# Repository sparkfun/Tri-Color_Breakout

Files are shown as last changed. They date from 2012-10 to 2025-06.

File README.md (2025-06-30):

Tri-Color LED Breakout Kit
==========================

[Tri-Color LED Breakout Kit  
*Tri-Color LED Breakout Kit (KIT-10111)*](https://www.sparkfun.com/products/10111)

A simple breakout board to control three larger LEDs. Each 10mm LED requires 65-75mA to drive the LED at full brightness. This breakout uses basic NPN transistors and current limiting resistors to push each LED to its limit.

The hardware was designed in Eagle v6.3

Repository Contents
-------------------
* **/Firmware** - Eample Arduino sketch
* **/Hardware** - All Eagle design files (.brd, .sch)

Product Versions
----------------

* [KIT-10111](https://www.sparkfun.com/products/10111) - The current version of the Tri-Color LED Breakout Kit in standard OEM packaging.
* [KIT-10778](https://www.sparkfun.com/products/10778) - The current version of the Tri-Color LED Breakout Kit in a retail-ready plastic clam shell.

License Information
-------------------

The hardware is released under [Creative Commons Share-alike 3.0](http://creativecommons.org/licenses/by-sa/3.0/).  
All other code is open source hardware so please feel free to do anything you want with it; you buy me a beer if you use this and we meet someday ([Beerware license](http://en.wikipedia.org/wiki/Beerware)).

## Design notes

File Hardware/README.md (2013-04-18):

# What Are these Files?

The .sch and .brd files hare are Eagle CAD schematic and PCB design files.

These files were created with Eagle 6.3.0, you'll need Eagle 6.3 or later to open them up. There is a free, lite, version of Eagle available from [cadsoftusa.com](cadsoftusa.com).

# License

This product is open source! These Eagle files are released under the Creative Commons Share-Alike Attribution license ([CC BY-SA 3.0](http://creativecommons.org/licenses/by-sa/3.0/us/)).

Please use, reuse, and modify these files as you see fit. Please maintain attribution and release anything derivative under the same license.

- Your friends at SparkFun.

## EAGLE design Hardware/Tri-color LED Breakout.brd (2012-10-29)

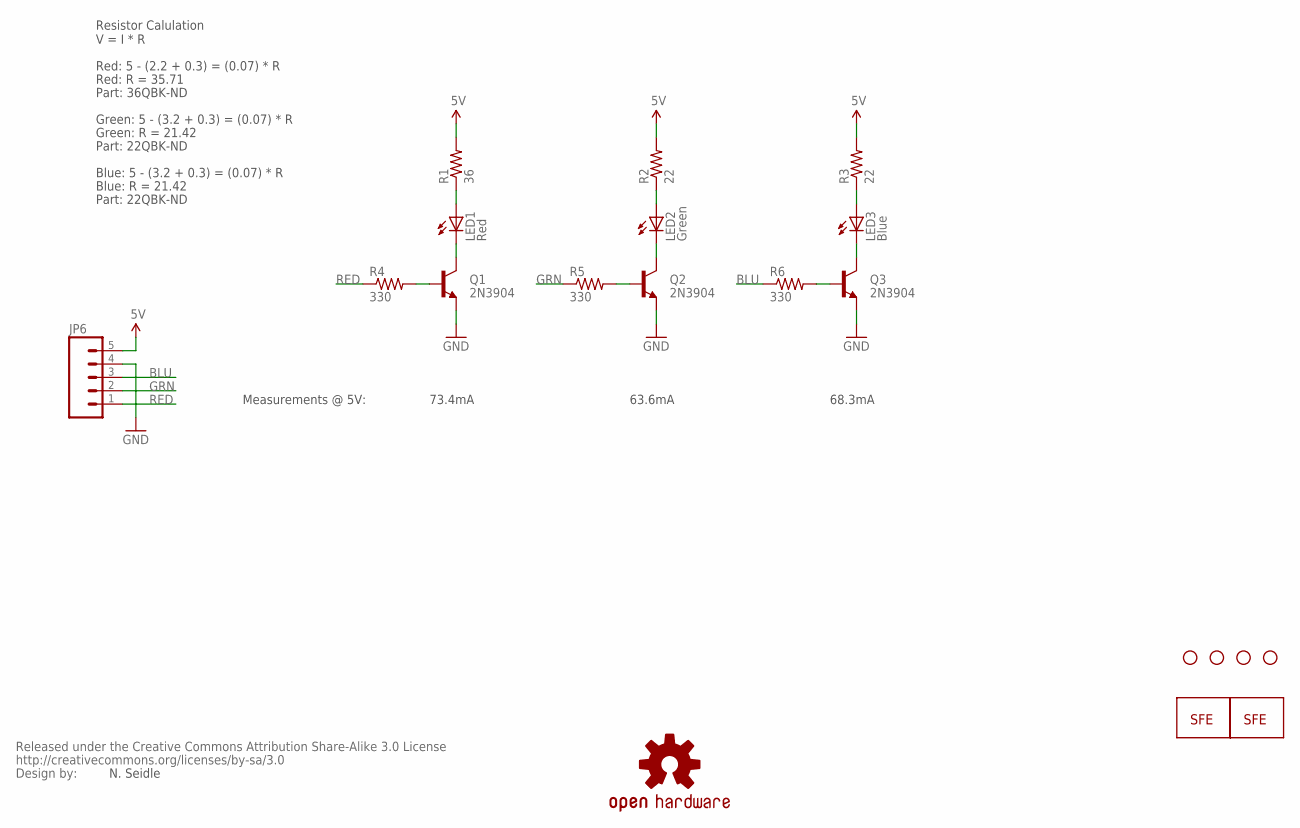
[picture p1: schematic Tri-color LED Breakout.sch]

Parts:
JP1, JP2, JP3, JP4: STAND-OFF
JP5, JP7: LOGO-SFESK; SFE-LOGO-FLAME
JP6: M05PTH; 1X05
LED1: Red; LED10MM
LED2: Green; LED10MM
LED3: Blue; LED10MM
Q1, Q2, Q3: 2N3904; TO-92
R1: 36; AXIAL-0.4
R2, R3: 22; AXIAL-0.4
R4, R5, R6: 330; AXIAL-0.3
U$1: CREATIVE_COMMONS
U$6: OSHW-LOGOS; OSHW-LOGO-S

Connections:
5V: JP6.5, R1.P$2 (2), R2.P$2 (2), R3.P$2 (2)
BLU: JP6.3, R6.P$1 (1)
GND: JP6.4, Q1.1 (E), Q2.1 (E), Q3.1 (E)
GRN: JP6.2, R5.P$1 (1)
unnamed: LED2.A, R2.P$1 (1)
unnamed: LED3.A, R3.P$1 (1)
unnamed: LED1.A, R1.P$1 (1)
unnamed: LED1.C, Q1.3 (C)
unnamed: LED2.C, Q2.3 (C)
unnamed: LED3.C, Q3.3 (C)
unnamed: Q1.2 (B), R4.P$2 (2)
unnamed: Q2.2 (B), R5.P$2 (2)
unnamed: Q3.2 (B), R6.P$2 (2)
RED: JP6.1, R4.P$1 (1)

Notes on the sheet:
N. Seidle
Resistor Calulation V = I * R
Red: 5 - (2.2 + 0.3) = (0.07) * R
Red: R = 35.71
Green: 5 - (3.2 + 0.3) = (0.07) * R
Green: R = 21.42
Blue: 5 - (3.2 + 0.3) = (0.07) * R
Blue: R = 21.42
Part: 36QBK-ND
Part: 22QBK-ND
Measurements @ 5V:
73.4mA
63.6mA
68.3mA

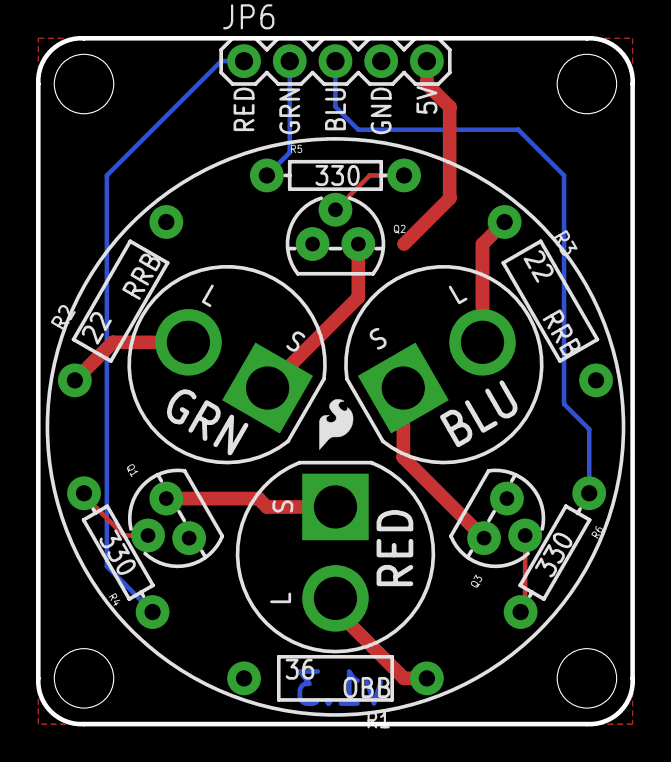
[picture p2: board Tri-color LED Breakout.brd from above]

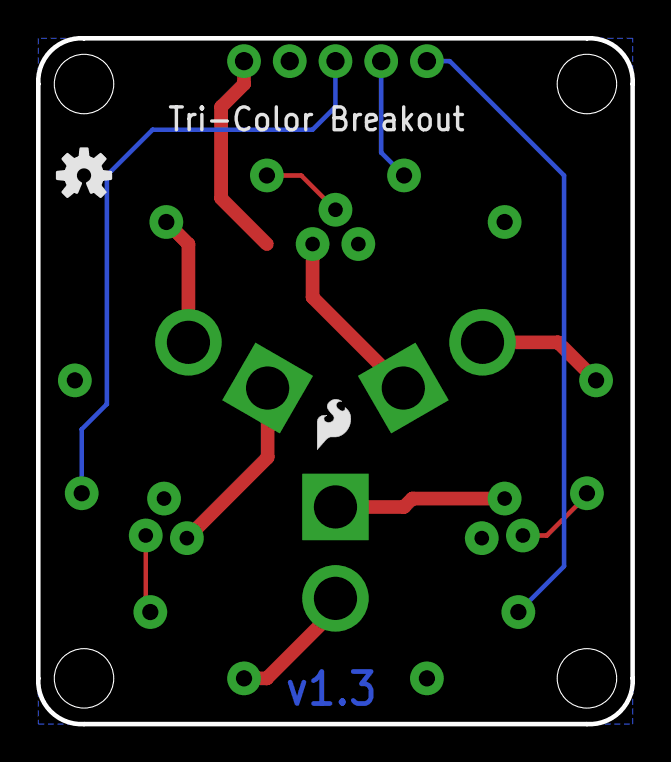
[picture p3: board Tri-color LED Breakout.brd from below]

Board: 2 copper layers, 33.0 x 38.1 mm, 21 parts (2 on the bottom side), 14 nets.

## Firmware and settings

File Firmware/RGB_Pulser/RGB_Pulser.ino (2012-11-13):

/*
 11-12-2012
 Spark Fun Electronics
 Nathan Seidle
 
 This code is public domain but you buy me a beer if you use this and we meet someday (Beerware license).
 
 Tri-Color Breakout is a board with a very high power red, green, and blue LED, controlled via transistors.
 We use the PWM outputs of an Arduino to mix these bright lights. I recommend you cover up the RGB LEDs with
 some sort of light diffuser. Using a white sheet of paper will save you from a migraine. Or if you really
 want to get crazy: http://www.google.com/#hl=en&q=white+plastic+acrylic+globe+lamp
  
 To get this code to work, attached an Tri-Color breakout to an Arduino Uno using the following pins:
 Pin 9 on Uno to RED on Tri-color Breakout
 Pin 10 on Uno to GRN on Tri-color Breakout
 Pin 11 on Uno to BLU on Tri-color Breakout
 VIN to PWR
 GND to GND
 
 Note: This code will output debug statements at 9600bps.
 
 This is closely related to the RGB circuit of the SparkFun Inventor's Kit circuit.
*/

//LED leads connected to PWM pins
const int RED_LED_PIN = 9;
const int GREEN_LED_PIN = 10;
const int BLUE_LED_PIN = 11;

//Length of time we spend showing each color
const int DISPLAYTIME = 500; // In milliseconds

//How quickly do we want to get to the next color?
const int STEPS = 200; //Amount of grace we take from getting from old to new. 200 works well.
const int STEPVALUE = 5; //How quickly we takes those steps. 1-10 works well.

long newColor;
long oldColor;

void setup()
{
  Serial.begin(9600);
  randomSeed(analogRead(0));
}

void loop()
{
  oldColor = newColor; //Remember the old color so that we can slowly mix from old to new

  newColor = random(0xFFFFFF); //Pick a random number between 0 and 16 million
  //8 bits are for red, 8 for green, 8 for blue

  //Push more values to off, 25% chance
  if(random(100) < 25) newColor = newColor & 0xFFFF00; //Turn blue off
  if(random(100) < 25) newColor = newColor & 0xFF00FF; //Turn green off
  if(random(100) < 25) newColor = newColor & 0x00FFFF; //Turn red off

  //Now that we have a new color, let's go to it!
  setColor(oldColor, newColor); //Move slowly from old color to new color

  Serial.print("Old:");
  Serial.print(oldColor, HEX);
  Serial.print(" New:");
  Serial.println(newColor, HEX);

  delay(DISPLAYTIME); //Wait an amount of time between color changes
}

//This function slowly changes the outputs from the previous color to the new color
//The two inputs are 32-bits. 8 bits are red, 8 bits green, 8 bits blue. 8 bits are unused.
//This allows us to drift between colors without the jarring color changes
void setColor(unsigned long oldClr, unsigned long newClr)
{
  /* 
   0x specifies the value is a hexadecimal number
   RR is a byte specifying the red intensity
   GG is a byte specifying the green intensity
   BB is a byte specifying the blue intensity
   */

  // Extract the intensity values from the hex triplet
  float oldRed = (oldClr >> 16) & 0xFF;
  float oldGreen = (oldClr >> 8) & 0xFF;
  float oldBlue = oldClr & 0xFF;

  byte newRed = (newClr >> 16) & 0xFF;
  byte newGreen = (newClr >> 8) & 0xFF;
  byte newBlue = newClr & 0xFF;

  //Find the difference between the old values and the new values
  int redDiff = abs(oldRed - newRed);
  int greenDiff = abs(oldGreen - newGreen);
  int blueDiff = abs(oldBlue - newBlue);

  //Figure out the steps we need to take to get to the new values
  float redStep = (float)redDiff / (STEPS/STEPVALUE); //50 / (STEPS/5) = 0;
  float greenStep = (float)greenDiff / (STEPS/STEPVALUE);
  float blueStep = (float)blueDiff / (STEPS/STEPVALUE);
  
  //Take care of a fringe case
  if (redStep == 0) redStep = 1;
  if (greenStep == 0) greenStep = 1;
  if (blueStep == 0) blueStep = 1;

  //Move Intensity1 towards Intensity2
  for(int fadeSteps = 0 ; fadeSteps <= STEPS ; fadeSteps += STEPVALUE)
  {
    //if less, then add
    //if more, then subtract
    //if equal, do nothing

    if(oldRed == newRed) ; //Do nothing
    else if(oldRed < newRed) oldRed += redStep;
    else if(oldRed > newRed)
    {
      if(oldRed > redStep) oldRed -= redStep;
      else if(oldRed > 0) oldRed--;
    }

    if(oldGreen == newGreen) ; //Do nothing
    else if(oldGreen < newGreen) oldGreen += greenStep;
    else if(oldGreen > newGreen)
    {
      if(oldGreen > greenStep) oldGreen -= greenStep;
      else if(oldGreen > 0) oldGreen--;
    }

    if(oldBlue == newBlue) ; //Do nothing
    else if(oldBlue < newBlue) oldBlue += blueStep;
    else if(oldBlue > newBlue)
    {
      if(oldBlue > blueStep) oldBlue -= blueStep;
      else if(oldBlue > 0) oldBlue--;
    }

    //Some interesting case corrections
    if(oldRed > 255) oldRed = 255;
    if(oldBlue > 255) oldBlue = 255;
    if(oldGreen > 255) oldGreen = 255;
    if(oldRed < 0) oldRed = 0;
    if(oldBlue < 0) oldBlue = 0;
    if(oldGreen < 0) oldGreen = 0;

    analogWrite(RED_LED_PIN, oldRed);
    analogWrite(GREEN_LED_PIN, oldGreen);
    analogWrite(BLUE_LED_PIN, oldBlue); 

    /*Serial.print("redDiff:");
     Serial.print(blueDiff, DEC);
     Serial.print(" redStep:");
     Serial.print(blueStep, 2);
     Serial.print(" oldRed:");
     Serial.print(oldBlue, 2);
     Serial.print(" newRed:");
     Serial.println(newBlue, DEC);*/

    delay(45); //45 miliseconds between steps
  }
}

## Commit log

2012-10-22 Original commit at v1.2. Problem with NPN configuration.
    [Tri-color LED Breakout-v12.brd, Tri-color LED Breakout-v12.sch]
2012-10-22 New v1.3. Corrected NPN configuration. Added version # to PCB.
    NPN transistors are now correctly on the bottom side of the circuit.
    This is what happens when you let a CEO design circuits.
    [Tri-color LED Breakout-v13.brd, Tri-color LED Breakout-v13.sch]
2012-10-22 Limiting resistors updated.
    Need to order 36QBK-ND and 22QBK-ND.
2012-10-29 Updating gitignore. Removing incremental backup files.
    [Tri-color LED Breakout-v13.GBL, Tri-color LED Breakout-v13.GBO, Tri-color LED Breakout-v13.GBP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]
2012-10-29 Added OSHW logo to board. Added BOM.
    [Tri-color LED Breakout-v13.brd, Tri-color LED Breakout-v13.sch]
2012-11-13 Protos works. Added measurements to schematic.
    [Tri-color LED Breakout-v13.sch]
2012-11-13 Proto works. Added measurements to schematic.
2012-11-13 Added example sketch. Moved layout to subdirectory.
    Example sketch is a good example of pulsing LEDs from one color to the
    next.
    [Tri-color LED Breakout-v12.brd, Tri-color LED Breakout-v12.sch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]
2013-04-18 Cleaned up repo structure and deleted old board files
    [Tri-color LED Breakout-v12.brd, Tri-color LED Breakout-v12.sch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]

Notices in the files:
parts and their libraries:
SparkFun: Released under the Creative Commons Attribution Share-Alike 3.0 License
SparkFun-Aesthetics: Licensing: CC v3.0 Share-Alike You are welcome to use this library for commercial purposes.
